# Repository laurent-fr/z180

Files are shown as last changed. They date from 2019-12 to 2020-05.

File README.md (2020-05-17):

# Micro Z180 homebrew computer

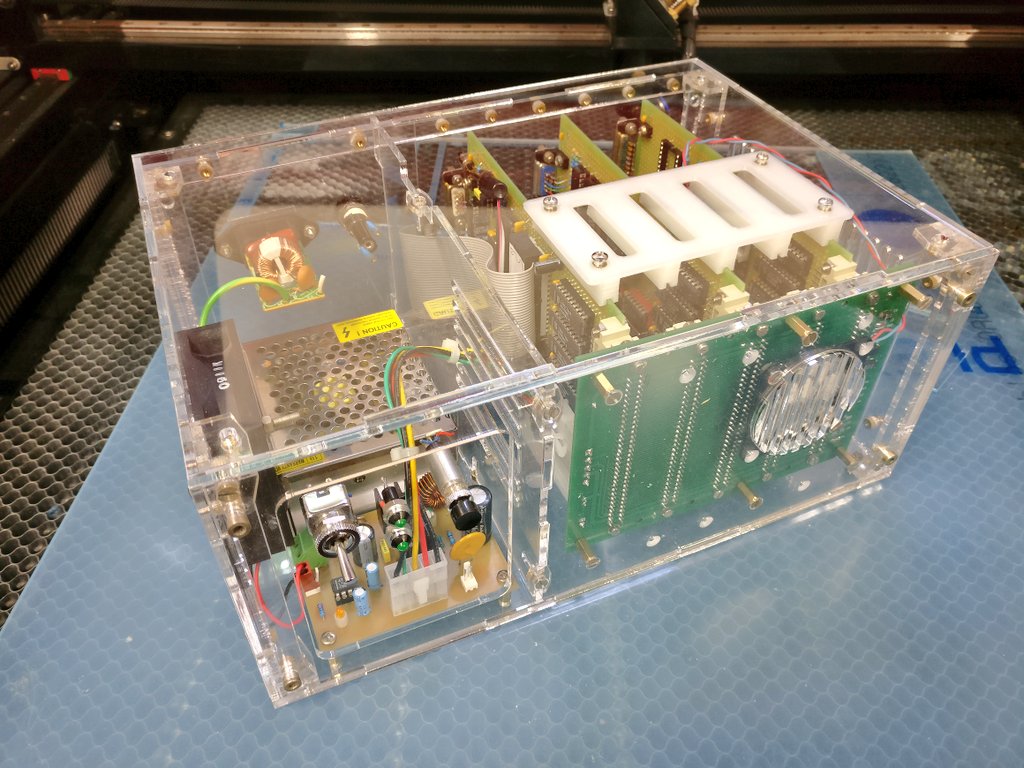
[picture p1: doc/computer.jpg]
The computer


*This is my attempt to create a 80's style computer based on the Zilog Z180 CPU.*

The goal is to build from scratch a complete computer, with  keyboard, video display, and mass storage. The software will be Microsoft BASIC and CP/M. Think of it as a crossover between an Amstrad CPC and an IBM PC 5150 !

The computer is designed around STEBUS, which is an old but well designed 8-bits industry-standard bus (https://en.wikipedia.org/wiki/STEbus). 

For now there are 5 cards :

 * PSU : the power supply, which takes 12v as input and generates +5v and -12v 
 * BUS : the STEBUS base board, with 5 slots and active termination
 * CPU : The main CPU board, with 2 RS-232 connectors
 * VDU : Video display unit, VGA text-only 80x25 with 16 colors, and 8 fonts selectable via jumpers on the board
 * MIO : Multi I/O, including PS/2 keyboard, Real time clock, Sound , Compact flash and Parallel port
 
 There are 3 main folders in this reposirory :
 
 * enclosure : all the files needed to build the case, which is laser-cut 3mm transparent acrylic (all parts are smaller than 200x300 mm), with a 3D printed part to mechanicaly guide the boards.
 * hardware : the description of all boards (very incomplete for now !)
 * software : Tests, BIOS, BASIC, and CP/M (coming soon !)
 
 ## Licenses
 
All the software is GPL v2, and all the hardware is CC-BY-NC-SA
 
 ## Status of the computer
 
 **This is a work-in-progress !**
 
 For now the computer is running BASIC with the PS/2 keyboard and integrated video display. There are still some rough edges but we are almost here.
 
 Some files are not yet on the repository because the computer was designed with paper and pencil !

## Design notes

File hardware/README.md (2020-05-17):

# Hardware

## Software needed

A few softwares are needed for reading/using the files in this folder :

* Kicad for reading the schematics and board layouts  https://kicad-pcb.org/ 
* Quartus 2 web edition for programming the Altera CPLDs https://fpgasoftware.intel.com/13.1/?edition=web
* WinCUPL for programming the GAL of the VDU board https://www.microchip.com/design-centers/fpgas-and-plds/splds-cplds/pld-design-resources

Optional :

* LTSPice, if you want to look at the few simulation files https://www.analog.com/en/design-center/design-tools-and-calculators/ltspice-simulator.html

## Hardware needed for running the computer

* An EPROM programmer. I use a Minipro TL866.
* A JTAG programmer for the CPLDs. I use the super cheap USB Blaster.

## Hardware for debugging the computer

It is not strictly needed to build the computer from the blueprints, but if something goes wrong the following could help :

* An EPROM simulator. The fastest way to test a new firmware ! Mine is a MemSIM2 from http://www.momik.pl/ and it works very well.
* A logic analyzer. Pick your favourite. Mine is a DSLogic.
* A good old oscilloscope is useful, too !

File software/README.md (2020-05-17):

# Software

To assemble the software, you will need SBASM available here : https://www.sbprojects.net/sbasm/

As it is written in Python, you will also need a Python interpreter ...

## BASIC

* nascom.basic.grant.searle : backup of NASCOM BASIC adapted by Grant Searle on his homebrew computer as found on http://searle.x10host.com/z80/SimpleZ80.html
(it's also the base software for RC2014 project)
* original : for reference NASCOM BASIC without modifications
* basic.asm : Grant Searle's version with small modifications by me (skip memory test, add colors)
* basic_boot.asm : the glue between basic.asm and the computer, with memory

## BIOS

The BIOS of the computer.

## CP/M

Work in progress !

## Include

Contains the constants for the Z180.

## mz180

This folder contains the main software for the computer. It allows to boot all-RAM BASIC and hopefully soon CP/M. 
The file eprom.hex is what you want to burn on the EPROM of the CPU board.

## Tests

All what you need to test the computer !

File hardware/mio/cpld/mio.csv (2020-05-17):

# Copyright (C) 1991-2012 Altera Corporation
# Your use of Altera Corporation's design tools | logic functions
# and other software and tools | and its AMPP partner logic
# functions | and any output files from any of the foregoing
# (including device programming or simulation files) | and any
# associated documentation or information are expressly subject
# to the terms and conditions of the Altera Program License
# Subscription Agreement | Altera MegaCore Function License
# Agreement | or other applicable license agreement | including
# without limitation | that your use is for the sole purpose of
# programming logic devices manufactured by Altera and sold by
# Altera or its authorized distributors. Please refer to the
# applicable agreement for further details.
# Quartus II 64-Bit Version 12.1 Build 177 11/07/2012 SJ Web Edition
# File: C:\Users\Laurent\Documents\altera\mio\output_files\mio.csv
# Generated on: Sun May 17 15:32:25 2020
# Note: The column header names should not be changed if you wish to import this .csv file into the Quartus II software.
To | Direction | Location | Fitter Location | Reserved
TCK | Input |  | PIN_32
TDI | Input |  | PIN_7
TDO | Output |  | PIN_38
TMS | Input |  | PIN_13
addr[4] | Input | PIN_4 | PIN_4
addr[3] | Input | PIN_41 | PIN_41
addr[2] | Input | PIN_40 | PIN_40
addr[1] | Input | PIN_39 | PIN_39
addr[0] | Input | PIN_37 | PIN_37
ce | Input | PIN_34 | PIN_34
clk | Input | PIN_43 | PIN_43
cm0 | Input | PIN_31 | PIN_31
cs_compactflash | Output | PIN_26 | PIN_26
cs_printer | Output | PIN_19 | PIN_19
cs_rtc | Output | PIN_21 | PIN_21
data[7] | Bidir | PIN_16 | PIN_16
data[6] | Bidir | PIN_11 | PIN_11
data[5] | Bidir | PIN_14 | PIN_14
data[4] | Bidir | PIN_9 | PIN_9
data[3] | Bidir | PIN_12 | PIN_12
data[2] | Bidir | PIN_8 | PIN_8
data[1] | Bidir | PIN_5 | PIN_5
data[0] | Bidir | PIN_6 | PIN_6
datack | Output | PIN_29 | PIN_29
int | Output | PIN_25 | PIN_25
kbd_clk | Input | PIN_18 | PIN_18
kbd_data | Input | PIN_20 | PIN_20
rd | Output | PIN_27 | PIN_27
reset | Input | PIN_33 | PIN_33
snd | Output | PIN_24 | PIN_24
wr | Output | PIN_28 | PIN_28
divclk | Unknown | PIN_2

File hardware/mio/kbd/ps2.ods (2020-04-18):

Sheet: Feuille1_2
touche | scancode | ascii | ascii+shift | ascii+altgr |  | scancode
 |  |  |  |  | 0 | 0
F9 | 01 |  |  |  | 1 | 1
 |  |  |  |  | 2 | 2
F5 | 03 |  |  |  | 3 | 3
F3 | 04 |  |  |  | 4 | 4
F1 | 05 |  |  |  | 5 | 5
F2 | 06 |  |  |  | 6 | 6
F12 | 07 |  |  |  | 7 | 7
 |  |  |  |  | 8 | 8
F10 | 09 |  |  |  | 9 | 9
F8 | 0a |  |  |  | 10 | A
F6 | 0b |  |  |  | 11 | B
F4 | 0c |  |  |  | 12 | C
tab | 0D | 9 |  |  | 13 | D
₂ | 0E |  |  |  | 14 | E
 |  |  |  |  | 15 | F
 |  |  |  |  | 16 | 10
 |  |  |  |  | 17 | 11
lshift | 12 |  |  |  | 18 | 12
 |  |  |  |  | 19 | 13
 |  |  |  |  | 20 | 14
a | 15 | 97 |  |  | 21 | 15
1 | 16 | 38 | 49 |  | 22 | 16
 |  |  |  |  | 23 | 17
 |  |  |  |  | 24 | 18
 |  |  |  |  | 25 | 19
w | 1A | 119 |  |  | 26 | 1A
s | 1B | 115 |  |  | 27 | 1B
q | 1C | 113 |  |  | 28 | 1C
z | 1D | 122 |  |  | 29 | 1D
2 | 1E |  | 50 | 126 | 30 | 1E
 |  |  |  |  | 31 | 1F
 |  |  |  |  | 32 | 20
c | 21 | 99 |  |  | 33 | 21
x | 22 | 120 |  |  | 34 | 22
d | 23 | 100 |  |  | 35 | 23
e | 24 | 101 |  |  | 36 | 24
4 | 25 | 38 | 52 | 123 | 37 | 25
3 | 26 | 34 | 51 | 35 | 38 | 26
 |  |  |  |  | 39 | 27
 |  |  |  |  | 40 | 28
space | 29 | 32 |  |  | 41 | 29
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

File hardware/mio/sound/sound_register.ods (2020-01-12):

 | Clk
 | 2000000
Freq | Register | Real Freq | Error
27,5 | 72727 | 27,5001031253867 | 0,00 %
29,1352350948806 | 68645 | 29,1354068031175 | 0,00 %
30,8677063285078 | 64793 | 30,86753198648 | 0,00 %
32,7031956625748 | 61156 | 32,7032507031199 | 0,00 %
34,647828872109 | 57724 | 34,6476335666274 | 0,00 %
36,708095989676 | 54484 | 36,7080243741282 | 0,00 %
38,8908729652601 | 51426 | 38,8908334305604 | 0,00 %
41,2034446141088 | 48540 | 41,2031314379893 | 0,00 %
43,6535289291255 | 45815 | 43,6538251664302 | 0,00 %
46,2493028389543 | 43244 | 46,2491906391638 | 0,00 %
48,9994294977187 | 40817 | 48,99919151334 | 0,00 %
51,9130871974932 | 38526 | 51,9129938223537 | 0,00 %
55 | 36364 | 54,9994500054999 | 0,00 %
58,2704701897613 | 34323 | 58,2699647466713 | 0,00 %
61,7354126570155 | 32396 | 61,7360167921966 | 0,00 %
65,4063913251497 | 30578 | 65,4065014062398 | 0,00 %
69,2956577442181 | 28862 | 69,2952671332548 | 0,00 %
73,4161919793519 | 27242 | 73,4160487482564 | 0,00 %
77,7817459305203 | 25713 | 77,7816668611208 | 0,00 %
82,4068892282175 | 24270 | 82,4062628759786 | 0,00 %
87,307057858251 | 22908 | 87,3057447180024 | 0,00 %
92,4986056779087 | 21622 | 92,4983812783276 | 0,00 %
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

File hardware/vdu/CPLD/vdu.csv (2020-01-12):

# Copyright (C) 1991-2012 Altera Corporation
# Your use of Altera Corporation's design tools | logic functions
# and other software and tools | and its AMPP partner logic
# functions | and any output files from any of the foregoing
# (including device programming or simulation files) | and any
# associated documentation or information are expressly subject
# to the terms and conditions of the Altera Program License
# Subscription Agreement | Altera MegaCore Function License
# Agreement | or other applicable license agreement | including
# without limitation | that your use is for the sole purpose of
# programming logic devices manufactured by Altera and sold by
# Altera or its authorized distributors. Please refer to the
# applicable agreement for further details.
# Quartus II 64-Bit Version 12.1 Build 177 11/07/2012 SJ Web Edition
# File: C:\Users\Laurent\Documents\altera\vdu\vdu.csv
# Generated on: Sun Jan 12 18:32:22 2020
# Note: The column header names should not be changed if you wish to import this .csv file into the Quartus II software.
To | Direction | Location | Fitter Location | Reserved
TCK | Input |  | PIN_32
TDI | Input |  | PIN_7
TDO | Output |  | PIN_38
TMS | Input |  | PIN_13
addr[10] | Output | PIN_20 | PIN_20
addr[9] | Output | PIN_21 | PIN_21
addr[8] | Output | PIN_18 | PIN_18
addr[7] | Output | PIN_19 | PIN_19
addr[6] | Output | PIN_16 | PIN_16
addr[5] | Output | PIN_14 | PIN_14
addr[4] | Output | PIN_11 | PIN_11
addr[3] | Output | PIN_12 | PIN_12
addr[2] | Output | PIN_9 | PIN_9
addr[1] | Output | PIN_8 | PIN_8
addr[0] | Output | PIN_6 | PIN_6
blank | Output | PIN_5 | PIN_5
clk | Input | PIN_43 | PIN_43
cload | Output | PIN_4 | PIN_4
cs | Input | PIN_33 | PIN_33
datack | Output | PIN_29 | PIN_29
hsync | Output | PIN_40 | PIN_40
row[3] | Output | PIN_25 | PIN_25
row[2] | Output | PIN_24 | PIN_24
row[1] | Output | PIN_27 | PIN_27
row[0] | Output | PIN_26 | PIN_26
vclk | Input | PIN_2 | PIN_2
vsync | Output | PIN_41 | PIN_41

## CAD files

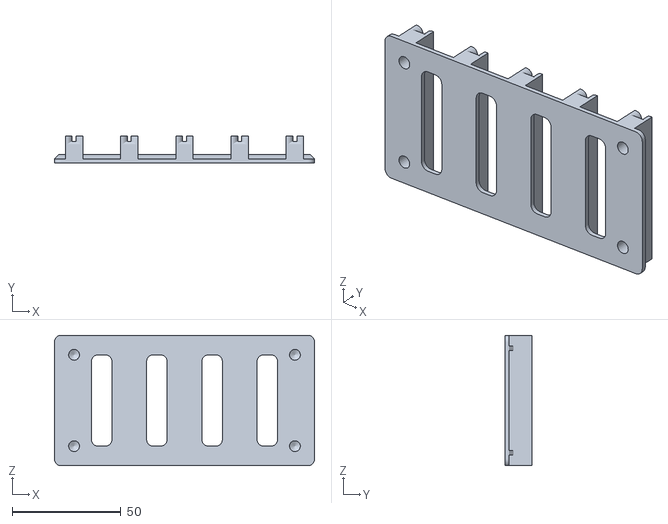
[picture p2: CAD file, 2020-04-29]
enclosure/3dprint/card_guide.stl
119.6 x 12.2 x 60.0

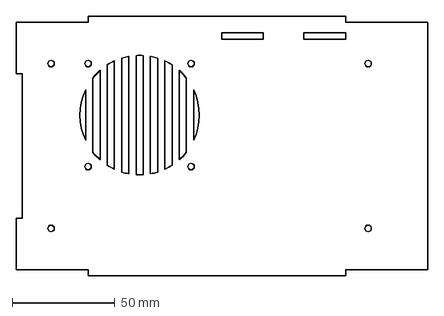
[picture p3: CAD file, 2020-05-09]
enclosure/lasercut/side_left.dxf
200.0 x 126.0 mm

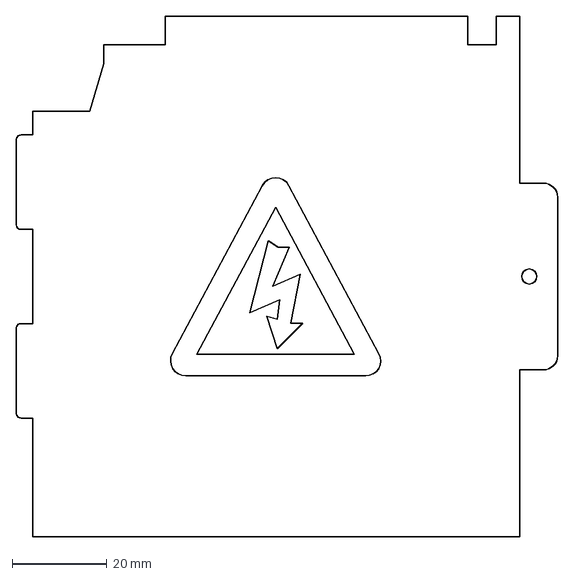
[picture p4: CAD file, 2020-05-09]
enclosure/lasercut/top_psu.dxf
114.5 x 110.0 mm

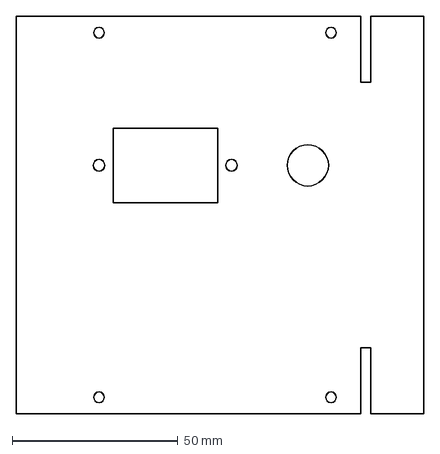
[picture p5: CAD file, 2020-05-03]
enclosure/lasercut/back_psu.dxf
123.0 x 120.0 mm

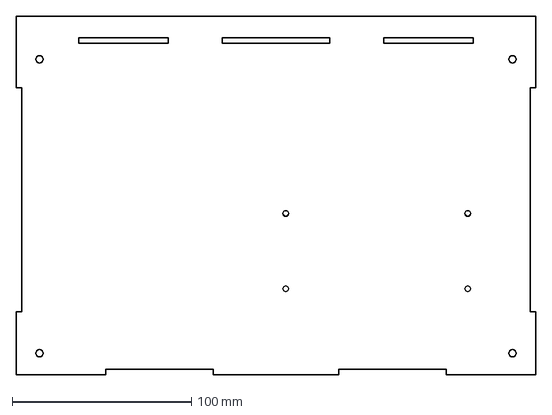
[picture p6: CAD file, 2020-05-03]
enclosure/lasercut/top.dxf
290.0 x 200.0 mm

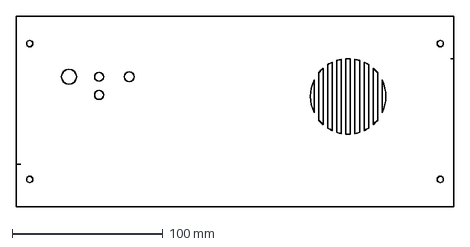
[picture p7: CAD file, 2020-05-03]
enclosure/lasercut/front.dxf
290.0 x 126.0 mm

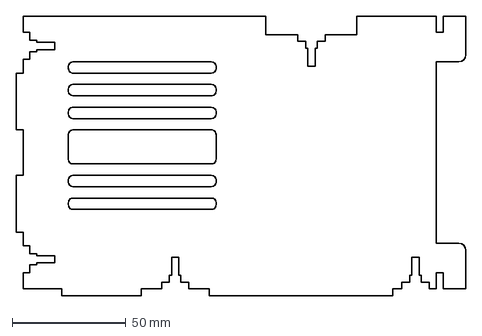
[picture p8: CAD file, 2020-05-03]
enclosure/lasercut/inner_wall.dxf
198.0 x 123.0 mm

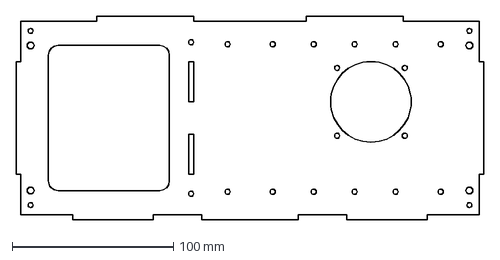
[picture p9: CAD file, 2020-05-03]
enclosure/lasercut/front_in.dxf
290.0 x 126.0 mm

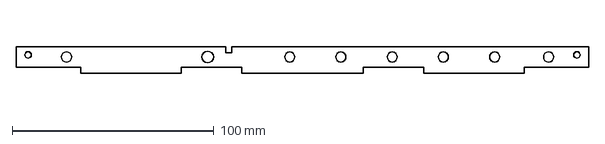
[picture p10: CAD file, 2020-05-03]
enclosure/lasercut/back.dxf
284.0 x 13.0 mm

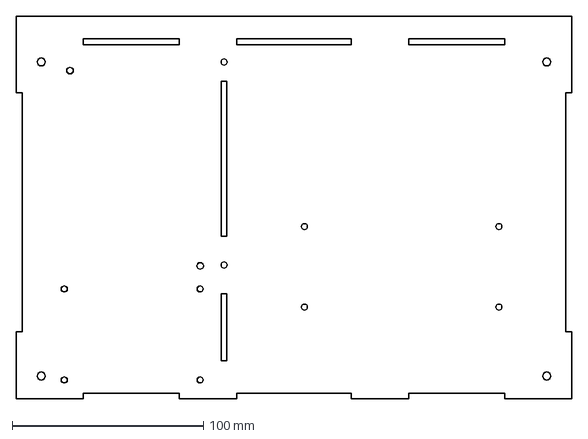
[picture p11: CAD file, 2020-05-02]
enclosure/lasercut/bottom.dxf
290.0 x 200.0 mm

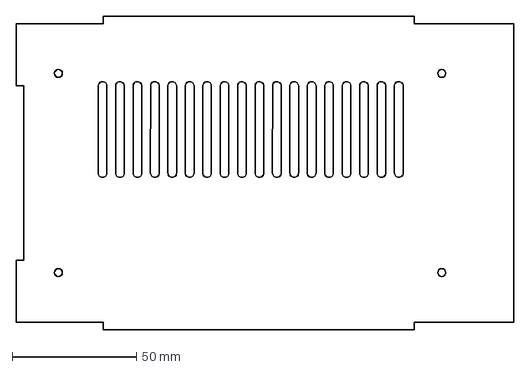
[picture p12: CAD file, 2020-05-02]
enclosure/lasercut/side_right.dxf
200.0 x 126.0 mm

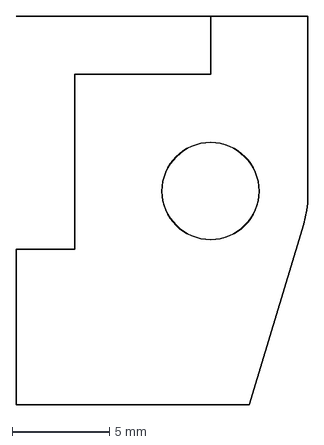
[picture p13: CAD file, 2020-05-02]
enclosure/lasercut/corner_top_bottom.dxf
15.0 x 20.0 mm

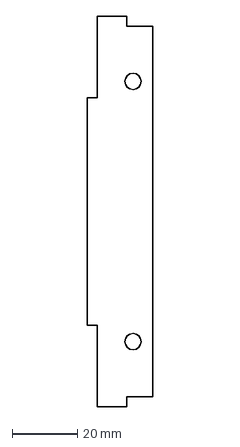
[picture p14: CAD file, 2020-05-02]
enclosure/lasercut/corner_side.dxf
20.0 x 120.0 mm

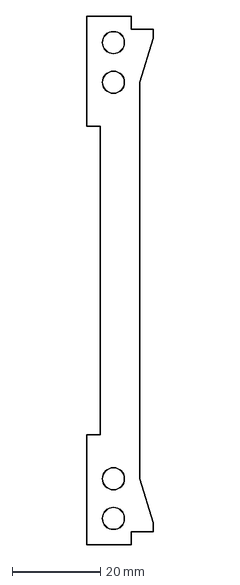
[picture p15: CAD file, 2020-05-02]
enclosure/lasercut/corner_front.dxf
15.0 x 120.0 mm

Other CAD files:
enclosure/lasercut/bolt.dxf

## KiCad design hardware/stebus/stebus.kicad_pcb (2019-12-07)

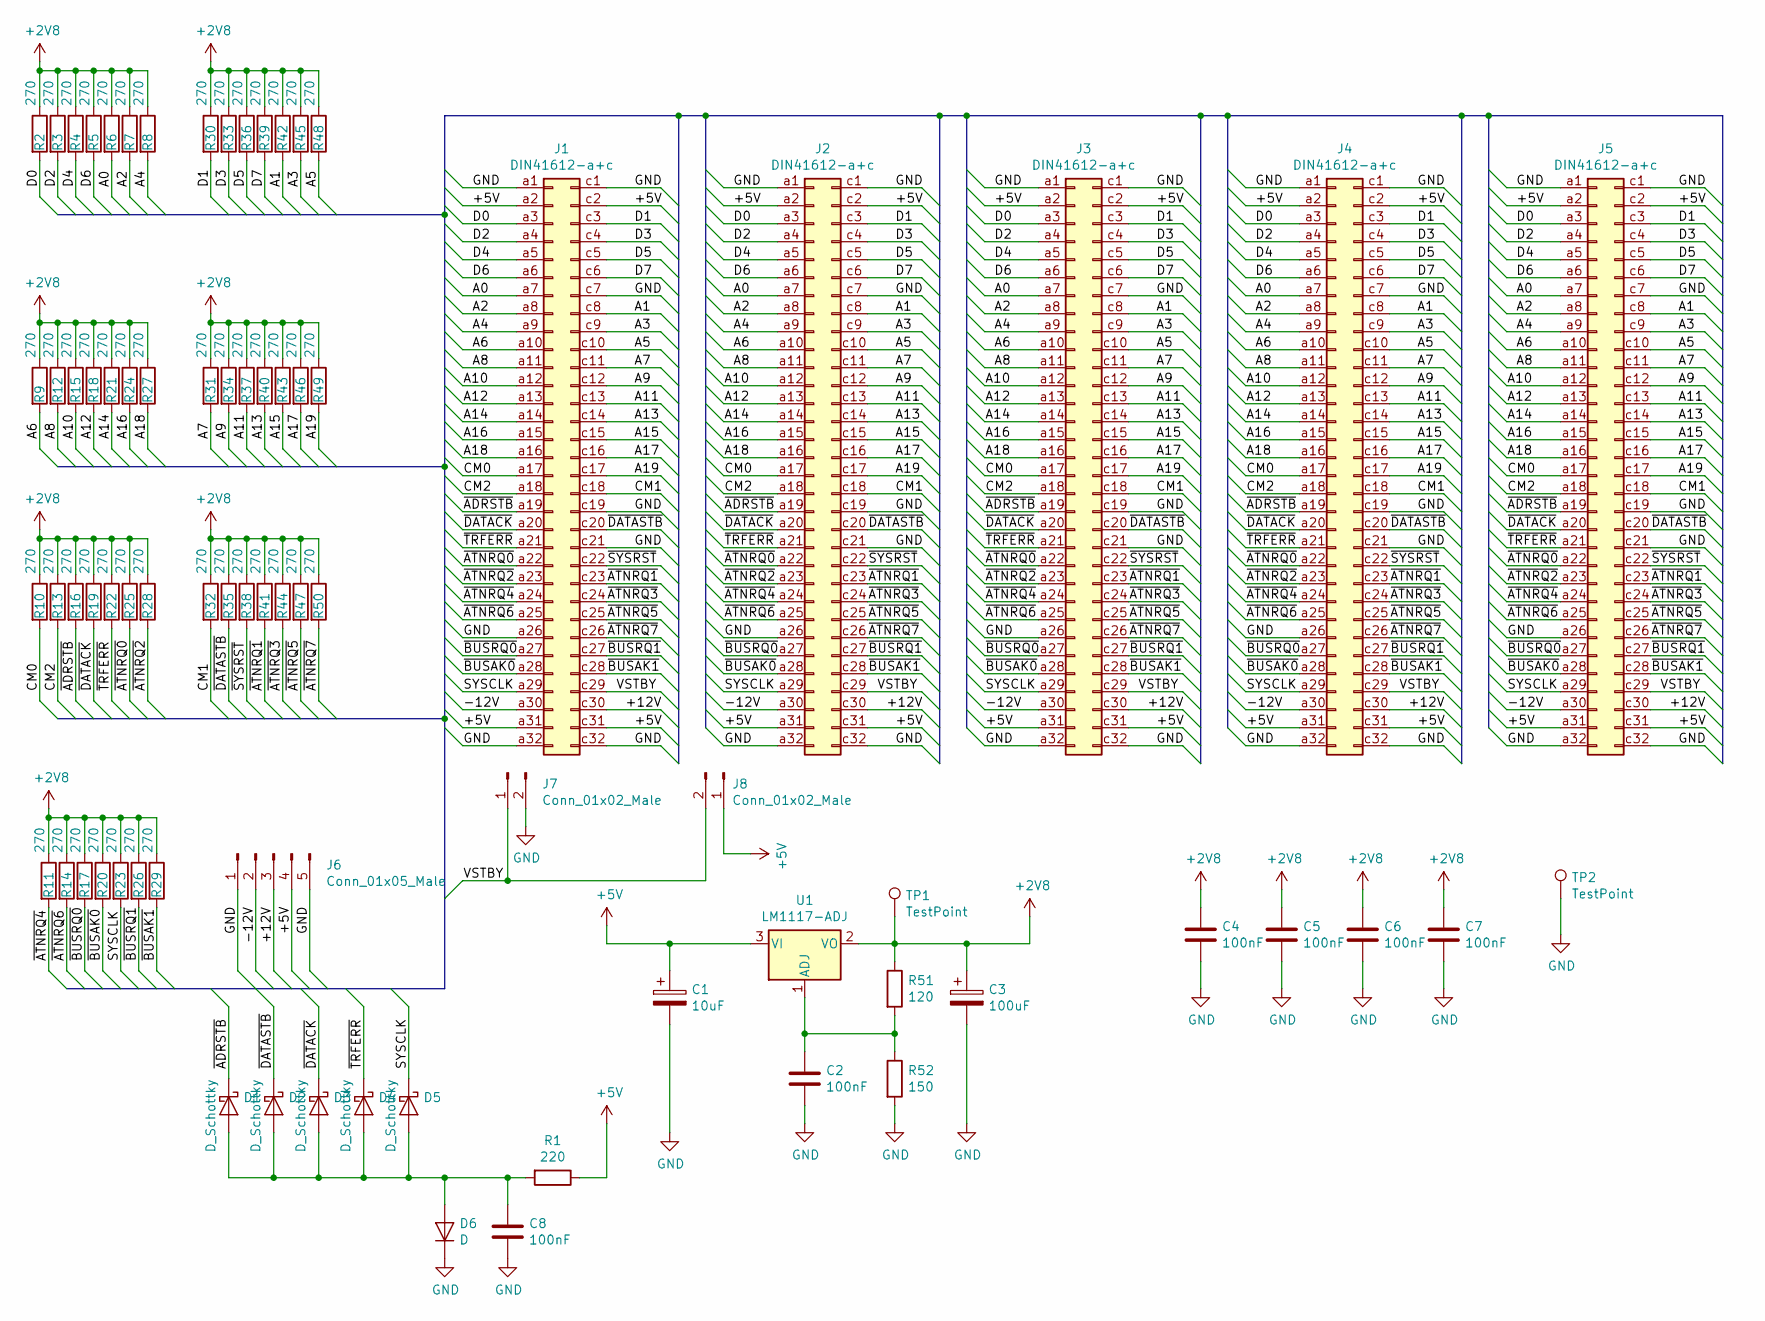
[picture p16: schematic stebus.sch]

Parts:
C1: 10uF; C_1210_HandSoldering
C2, C4, C5, C6, C7, C8: 100nF; C_1206_HandSoldering
C3: 100uF; C_1812_HandSoldering
D1, D2, D3, D4, D5: D_Schottky; D_SMA
D6: D; D_MiniMELF_Handsoldering
J1, J2, J3, J4, J5: DIN41612-a+c; Socket_DIN41612-CaseC1-AC-Female-64Pin-2rows
J6: Conn_01x05_Male; Molex_MiniFit-JR-5556-10A_1x05x4.20mm_Straight
J7: Conn_01x02_Male; Molex_KK-6410-02_02x2.54mm_Straight
J8: Conn_01x02_Male; Pin_Header_Straight_1x02_Pitch2.54mm
R1: 220; R_1206_HandSoldering
R2, R3, R4, R5, R6, R7, R8, R9, R10, R11, R12, R13, R14, R15, R16, R17, R18, R19, R20, R21, R22, R23, R24, R25, R26, R27, R28, R29, R30, R31, R32, R33, R34, R35, R36, R37, R38, R39, R40, R41, R42, R43, R44, R45, R46, R47, R48, R49, R50: 270; R_1206_HandSoldering
R51: 120; C_1206_HandSoldering
R52: 150; C_1206_HandSoldering
TP1, TP2: TestPoint; Pin_Header_Straight_1x01_Pitch2.54mm
U1: LM1117-ADJ; SOT-223-3_TabPin2

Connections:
+2V8: C3.1, C4.1, C5.1, C6.1, C7.1, R2.1, R3.1, R4.1, R5.1, R6.1, R7.1, R8.1, R9.1, R10.1, R11.1, R12.1, R13.1, R14.1, R15.1, R16.1, R17.1, R18.1, R19.1, R20.1, R21.1, R22.1, R23.1, R24.1, R25.1, R26.1, R27.1, R28.1, R29.1, R30.1, R31.1, R32.1, R33.1, R34.1, R35.1, R36.1, R37.1, R38.1, R39.1, R40.1, R41.1, R42.1, R43.1, R44.1, R45.1, R46.1, R47.1, R48.1, R49.1, R50.1, R51.1, TP1.1, U1.2 (VO)
+5V: C1.1, J1.a2, J1.a31, J1.c2, J1.c31, J2.a2, J2.a31, J2.c2, J2.c31, J3.a2, J3.a31, J3.c2, J3.c31, J4.a2, J4.a31, J4.c2, J4.c31, J5.a2, J5.a31, J5.c2, J5.c31, J6.4, J8.1, R1.1, U1.3 (VI)
/+12V: J1.c30, J2.c30, J3.c30, J4.c30, J5.c30, J6.3
/-12V: J1.a30, J2.a30, J3.a30, J4.a30, J5.a30, J6.2
/A0: J1.a7, J2.a7, J3.a7, J4.a7, J5.a7, R6.2
/A1: J1.c8, J2.c8, J3.c8, J4.c8, J5.c8, R42.2
/A2: J1.a8, J2.a8, J3.a8, J4.a8, J5.a8, R7.2
/A3: J1.c9, J2.c9, J3.c9, J4.c9, J5.c9, R45.2
/A4: J1.a9, J2.a9, J3.a9, J4.a9, J5.a9, R8.2
/A5: J1.c10, J2.c10, J3.c10, J4.c10, J5.c10, R48.2
/A6: J1.a10, J2.a10, J3.a10, J4.a10, J5.a10, R9.2
/A7: J1.c11, J2.c11, J3.c11, J4.c11, J5.c11, R31.2
/A8: J1.a11, J2.a11, J3.a11, J4.a11, J5.a11, R12.2
/A9: J1.c12, J2.c12, J3.c12, J4.c12, J5.c12, R34.2
/A10: J1.a12, J2.a12, J3.a12, J4.a12, J5.a12, R15.2
/A11: J1.c13, J2.c13, J3.c13, J4.c13, J5.c13, R37.2
/A12: J1.a13, J2.a13, J3.a13, J4.a13, J5.a13, R18.2
/A13: J1.c14, J2.c14, J3.c14, J4.c14, J5.c14, R40.2
/A14: J1.a14, J2.a14, J3.a14, J4.a14, J5.a14, R21.2
/A15: J1.c15, J2.c15, J3.c15, J4.c15, J5.c15, R43.2
/A16: J1.a15, J2.a15, J3.a15, J4.a15, J5.a15, R24.2
/A17: J1.c16, J2.c16, J3.c16, J4.c16, J5.c16, R46.2
/A18: J1.a16, J2.a16, J3.a16, J4.a16, J5.a16, R27.2
/A19: J1.c17, J2.c17, J3.c17, J4.c17, J5.c17, R49.2
/CM0: J1.a17, J2.a17, J3.a17, J4.a17, J5.a17, R10.2
/CM1: J1.c18, J2.c18, J3.c18, J4.c18, J5.c18, R32.2
/CM2: J1.a18, J2.a18, J3.a18, J4.a18, J5.a18, R13.2
/D0: J1.a3, J2.a3, J3.a3, J4.a3, J5.a3, R2.2
/D1: J1.c3, J2.c3, J3.c3, J4.c3, J5.c3, R30.2
/D2: J1.a4, J2.a4, J3.a4, J4.a4, J5.a4, R3.2
/D3: J1.c4, J2.c4, J3.c4, J4.c4, J5.c4, R33.2
/D4: J1.a5, J2.a5, J3.a5, J4.a5, J5.a5, R4.2
/D5: J1.c5, J2.c5, J3.c5, J4.c5, J5.c5, R36.2
/D6: J1.a6, J2.a6, J3.a6, J4.a6, J5.a6, R5.2
/D7: J1.c6, J2.c6, J3.c6, J4.c6, J5.c6, R39.2
/SYSCLK: D5.1 (K), J1.a29, J2.a29, J3.a29, J4.a29, J5.a29, R23.2
/VSTBY: J1.c29, J2.c29, J3.c29, J4.c29, J5.c29, J7.1, J8.2
/~: J1.a25, J2.a25, J3.a25, J4.a25, J5.a25, R14.2
/~ADRSTB~: D1.1 (K), J1.a19, J2.a19, J3.a19, J4.a19, J5.a19, R16.2
/~ATNRQ0~: J1.a22, J2.a22, J3.a22, J4.a22, J5.a22, R25.2
/~ATNRQ1~: J1.c23, J2.c23, J3.c23, J4.c23, J5.c23, R41.2
/~ATNRQ2~: J1.a23, J2.a23, J3.a23, J4.a23, J5.a23, R28.2
/~ATNRQ3~: J1.c24, J2.c24, J3.c24, J4.c24, J5.c24, R44.2
/~ATNRQ4~: J1.a24, J2.a24, J3.a24, J4.a24, J5.a24, R11.2
/~ATNRQ5~: J1.c25, J2.c25, J3.c25, J4.c25, J5.c25, R47.2
/~ATNRQ7~: J1.c26, J2.c26, J3.c26, J4.c26, J5.c26, R50.2
/~BUSAK0~: J1.a28, J2.a28, J3.a28, J4.a28, J5.a28, R20.2
/~BUSAK1~: J1.c28, J2.c28, J3.c28, J4.c28, J5.c28, R29.2
/~BUSRQ0~: J1.a27, J2.a27, J3.a27, J4.a27, J5.a27, R17.2
/~BUSRQ1~: J1.c27, J2.c27, J3.c27, J4.c27, J5.c27, R26.2
/~DATACK~: D3.1 (K), J1.a20, J2.a20, J3.a20, J4.a20, J5.a20, R19.2
/~DATASTB~: D2.1 (K), J1.c20, J2.c20, J3.c20, J4.c20, J5.c20, R35.2
/~SYSRST~: J1.c22, J2.c22, J3.c22, J4.c22, J5.c22, R38.2
/~TRFERR~: D4.1 (K), J1.a21, J2.a21, J3.a21, J4.a21, J5.a21, R22.2
GND: C1.2, C2.2, C3.2, C4.2, C5.2, C6.2, C7.2, C8.2, D6.1 (K), J1.a1, J1.a26, J1.a32, J1.c1, J1.c7, J1.c19, J1.c21, J1.c32, J2.a1, J2.a26, J2.a32, J2.c1, J2.c7, J2.c19, J2.c21, J2.c32, J3.a1, J3.a26, J3.a32, J3.c1, J3.c7, J3.c19, J3.c21, J3.c32, J4.a1, J4.a26, J4.a32, J4.c1, J4.c7, J4.c19, J4.c21, J4.c32, J5.a1, J5.a26, J5.a32, J5.c1, J5.c7, J5.c19, J5.c21, J5.c32, J6.1, J6.5, J7.2, R52.2, TP2.1
unnamed: C2.1, R51.2, R52.1, U1.1 (ADJ)
unnamed: C8.1, D1.2 (A), D2.2 (A), D3.2 (A), D4.2 (A), D5.2 (A), D6.2 (A), R1.2

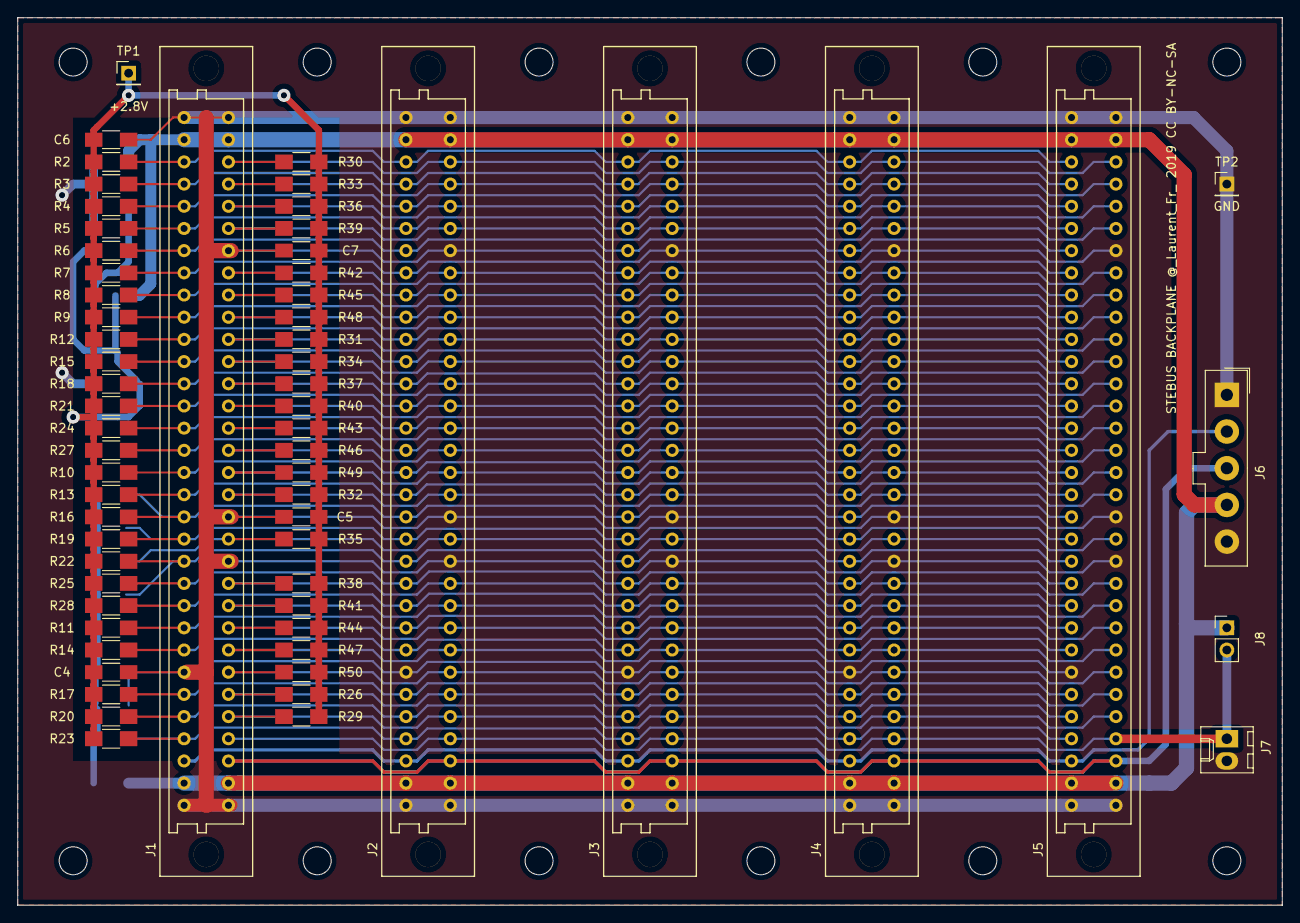
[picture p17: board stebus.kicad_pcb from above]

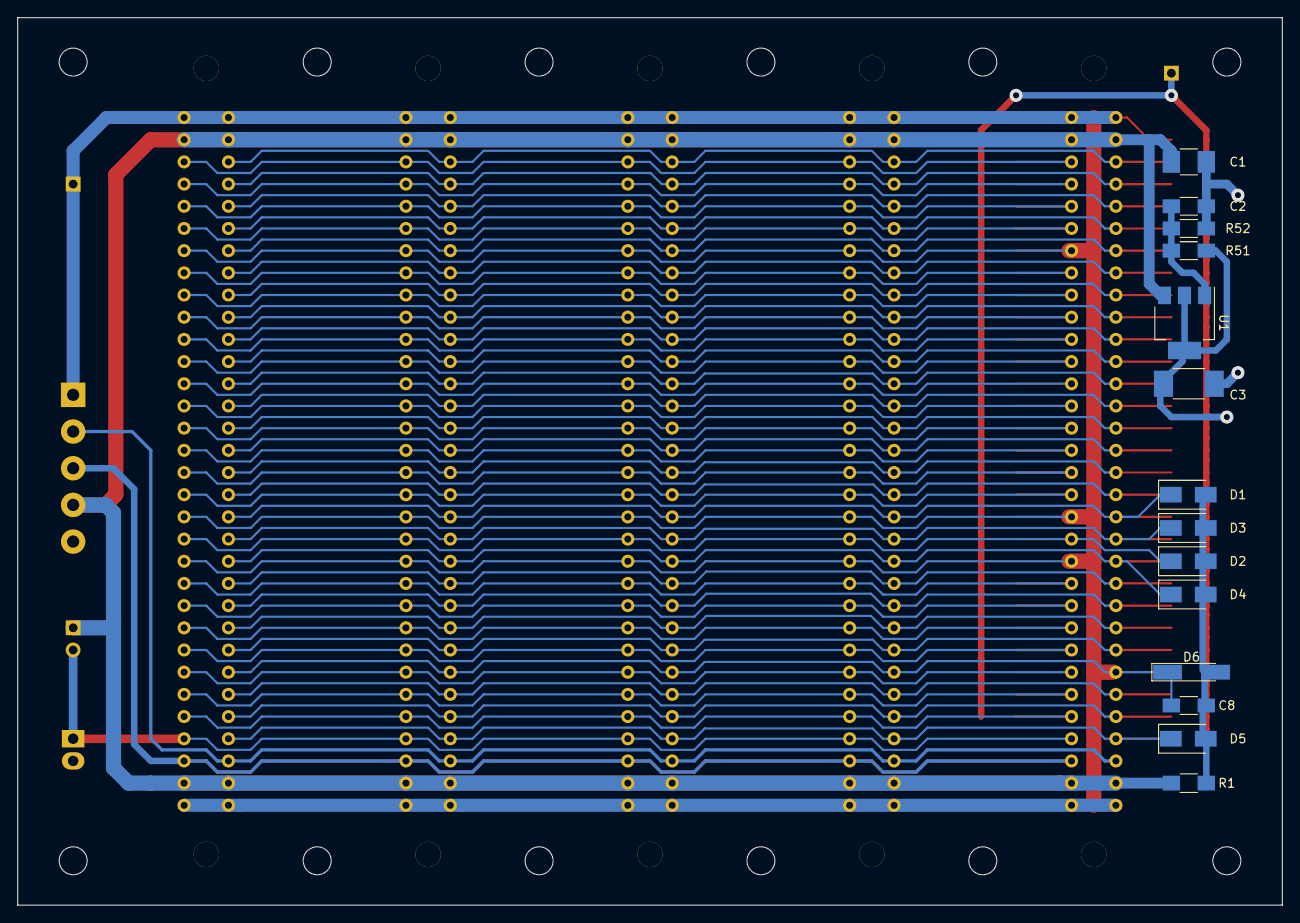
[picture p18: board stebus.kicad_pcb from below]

Board: 2 copper layers, 144.8 x 101.6 mm, 77 parts (14 on the bottom side), 57 nets.

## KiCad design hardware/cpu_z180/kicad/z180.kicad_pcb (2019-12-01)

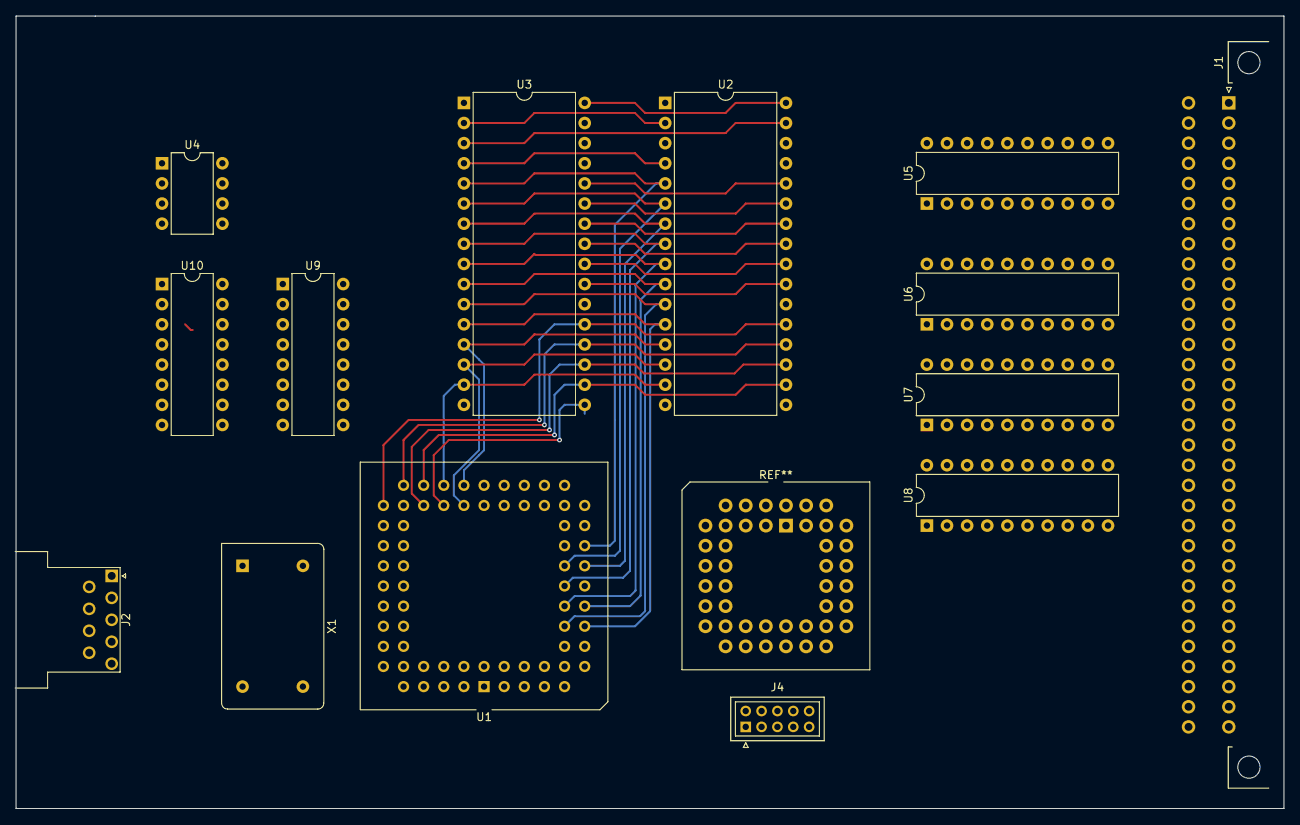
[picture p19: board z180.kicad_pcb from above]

Board: 2 copper layers, 160.0 x 100.0 mm, 14 parts (0 on the bottom side), 61 nets.

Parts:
J1: DIN41612-a+c; DIN41612_A+C_2x32_Horizontal
J2: DB9_Male_MountingHoles; DSUB-9_Male_Horizontal_P2.77x2.84mm_EdgePinOffset9.40mm
J4: Conn_02x05_Counter_Clockwise; JAE_LY20-10P-2T_2x05x2.00mm_Straight
U1: Z8S180CPU; PLCC-68_THT-Socket
U2: AS6C4008-55PCN; DIP-32_W15.24mm
U3: 27C010; DIP-32_W15.24mm
U4: TL7705B; DIP-8_W7.62mm
U5, U6, U7, U8: 74HC245; DIP-20_W7.62mm
U9, U10: MAX232; DIP-16_W7.62mm
X1: ACO-xxxMHz; Oscillator_DIP-14

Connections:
+5V: J1.a2, J1.a31, J1.c2, J1.c31, U1.34, U2.32, U3.31, U3.32, U5.20, X1.14
/bus-z180/BUS_A0: J1.a7, U6.18
/bus-z180/BUS_A1: J1.c8, U6.17
/bus-z180/BUS_A2: J1.a8, U6.16
/bus-z180/BUS_A3: J1.c9, U6.15
/bus-z180/BUS_A4: J1.a9, U6.14
/bus-z180/BUS_A5: J1.c10, U6.13
/bus-z180/BUS_A6: J1.a10, U6.12
/bus-z180/BUS_A7: J1.c11, U6.11
/bus-z180/BUS_A8: J1.a11, U7.18
/bus-z180/BUS_A9: J1.c12, U7.17
/bus-z180/BUS_A10: J1.a12, U7.16
/bus-z180/BUS_A11: J1.c13, U7.15
/bus-z180/BUS_A12: J1.a13, U7.14
/bus-z180/BUS_A13: J1.c14, U7.13
/bus-z180/BUS_A14: J1.a14, U7.12
/bus-z180/BUS_A15: J1.c15, U7.11
/bus-z180/BUS_A16: J1.a15, U8.18
/bus-z180/BUS_A17: J1.c16, U8.17
/bus-z180/BUS_A18: J1.a16, U8.16
/bus-z180/BUS_A19: J1.c17, U8.15
/bus-z180/BUS_D0: J1.a3, U5.18
/bus-z180/BUS_D1: J1.c3, U5.17
/bus-z180/BUS_D2: J1.a4, U5.16
/bus-z180/BUS_D3: J1.c4, U5.15
/bus-z180/BUS_D4: J1.a5, U5.14
/bus-z180/BUS_D5: J1.c5, U5.13
/bus-z180/BUS_D6: J1.a6, U5.12
/bus-z180/BUS_D7: J1.c6, U5.11
/~RD~: U1.67, U2.24, U3.24
/~WR~: U1.66, U2.29
A0: U1.14, U2.12, U3.12, U6.2
A1: U1.15, U2.11, U3.11, U6.3
A2: U1.16, U2.10, U3.10, U6.4
A3: U1.17, U2.9, U3.9, U6.5
A4: U1.19, U2.8, U3.8, U6.6
A5: U1.20, U2.7, U3.7, U6.7
A6: U1.21, U2.6, U3.6, U6.8
A7: U1.22, U2.5, U3.5, U6.9
A8: U1.23, U2.27, U3.27, U7.2
A9: U1.24, U2.26, U3.26, U7.3
A10: U1.25, U2.23, U3.23, U7.4
A11: U1.26, U2.25, U3.25, U7.5
A12: U1.27, U2.4, U3.4, U7.6
A13: U1.28, U2.28, U3.28, U7.7
A14: U1.29, U2.3, U3.29, U7.8
A15: U1.30, U2.31, U3.3, U7.9
A16: U1.31, U2.2, U3.2, U8.2
A17: U1.32, U2.30, U8.3
A18: U1.33, U2.1, U8.4
A19: U1.35, U8.5
D0: U1.37, U2.13, U3.13, U5.2
D1: U1.38, U2.14, U3.14, U5.3
D2: U1.39, U2.15, U3.15, U5.4
D3: U1.40, U2.17, U3.17, U5.5
D4: U1.41, U2.18, U3.18, U5.6
D5: U1.42, U2.19, U3.19, U5.7
D6: U1.43, U2.20, U3.20, U5.8
D7: U1.44, U2.21, U3.21, U5.9
GND: J1.a1, J1.a26, J1.a32, J1.c1, J1.c7, J1.c19, J1.c21, J1.c32, U1.1, U1.2, U1.18, U1.36, U2.16, U3.1, U3.16, U5.10, X1.7
unnamed: U1.4, X1.8

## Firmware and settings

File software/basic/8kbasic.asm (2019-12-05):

; NASCOM ROM BASIC Ver 4.7, (C) 1978 Microsoft
; Scanned from source published in 80-BUS NEWS from Vol 2, Issue 3
; (May-June 1983) to Vol 3, Issue 3 (May-June 1984)
; Adapted for the freeware Zilog Macro Assembler 2.10 to produce
; the original ROM code (checksum 0xA934). PA

.z180

.area CODE (ABS)


; MONITOR EQUATES (RESTART INSTRUCTIONS)

_ROUT   .equ     0xF7            ; ROUT - Output char in A
_BLNK   .equ     0x7BDF          ; SCAL BLINK - Get input char in A
_INLN   .equ     0x63DF          ; SCAL INLIN - Get input line
_MFLP   .equ     0x5FDF          ; SCAL MFLP - Toggle tape drv LED
_MRET   .equ     0x5BDF          ; SCAL MRET - Return to monitor
_READ   .equ     0x52DF          ; SCAL READ
_RIN    .equ     0x62DF          ; SCAL RIN - Scan for input char
_VRFY   .equ     0x56DF          ; SCAL VERIFY
_WRIT   .equ     0x57DF          ; SCAL WRITE

; GENERAL .equATES

UARTD   .equ     0x01             ; UART data port
UARTS   .equ     0x02             ; UART status port
CTRLC   .equ     0x03             ; Control "C"
CTRLG   .equ     0x07             ; Control "G"
BKSP    .equ     0x08             ; Back space
LF      .equ     0x0A             ; Line feed
CS      .equ     0x0C             ; Clear screen
CR      .equ     0x0D             ; Carriage return
CTRLO   .equ     0x0F             ; Control "O"
CTRLR   .equ     0x12             ; Control "R"
CTRLS   .equ     0x13             ; Control "S"
CTRLU   .equ     0x15             ; Control "U"
CTRLZ   .equ     0x1A             ; Control "Z"
ESC     .equ     0x1B             ; Escape
TBRK    .equ     0x1C             ; "T" monitor break
TBS     .equ     0x1D             ; "T" monitor back space
TCS     .equ     0x1E             ; "T" monitor clear screen
TCR     .equ     0x1F             ; "T" monitor carriage return
DEL     .equ     0x7F             ; Delete

; MONITOR LOCATIONS

MONSTT  .equ     0x0000           ; Start of monitor
STMON   .equ     0x000D           ; NAS-SYS initialisation
MFLP    .equ     0x0051           ; Flip tape LED ("T")
MONTYP  .equ     0x008D           ; Type of "T" monitor
T2DUMP  .equ     0x03D1           ; "T2" Dump routine
T4WR    .equ     0x0400           ; "T4" Write routine
T4READ  .equ     0x070C           ; "T4" Read routine
VDU     .equ     0x0800           ; NASCOM Video RAM base

; MONITOR WORK SPACE LOCATIONS

PORT0   .equ     0x0C00           ; Copy of output port 0
ARG1    .equ     0x0C0C           ; Argument 1
ARG2    .equ     0x0C0E           ; Argument 2
TCUR    .equ     0x0C18           ; "T" monitor cursor
CURSOR  .equ     0x0C29           ; NAS-SYS Cursor
ARGN    .equ     0x0C2B           ; Number of ARGS
TOUT    .equ     0x0C4A           ; "T" Output reflection
TIN     .equ     0x0C4D           ; "T" Input reflection
CIN     .equ     0x0C75           ; NAS-SYS Input table
NMI     .equ     0x0C7E           ; NAS-SYS NMI Jump

; BASIC WORK SPACE LOCATIONS

WRKSPC  .equ     0x1000           ; BASIC Work space
USR     .equ     0x1003           ; "USR (x)" jump
OUTSUB  .equ     0x1006           ; "OUT p,n"
OTPORT  .equ     0x1007           ; Port (p)
DIVSUP  .equ     0x1009           ; Division support routine
DIV1    .equ     0x100A           ; <- Values
DIV2    .equ     0x100E           ; <-   to
DIV3    .equ     0x1012           ; <-   be
DIV4    .equ     0x1015           ; <-inserted
SEED    .equ     0x1017           ; Random number seed
LSTRND  .equ     0x103A           ; Last random number
INPSUB  .equ     0x103E           ; #INP (x)" Routine
INPORT  .equ     0x103F           ; PORT (x)
NULLS   .equ     0x1041           ; Number of nulls
LWIDTH  .equ     0x1042           ; Terminal width
COMMAN  .equ     0x1043           ; Width for commas
NULFLG  .equ     0x1044           ; Null after input byte flag
CTLOFG  .equ     0x1045           ; Control "O" flag
LINESC  .equ     0x1046           ; Lines counter
LINESN  .equ     0x1048           ; Lines number
CHKSUM  .equ     0x104A           ; Array load/save check sum
NMIFLG  .equ     0x104C           ; Flag for NMI break routine
BRKFLG  .equ     0x104D           ; Break flag
RINPUT  .equ     0x104E           ; Input reflection
POINT   .equ     0x1051           ; "POINT" reflection (unused)
PSET    .equ     0x1054           ; "SET"   reflection
RESET   .equ     0x1057           ; "RESET" reflection
STRSPC  .equ     0x105A           ; Bottom of string space
LINEAT  .equ     0x105C           ; Current line number
BASTXT  .equ     0x105E           ; Pointer to start of program
BUFFER  .equ     0x1061           ; Input buffer
STACK   .equ     0x1066           ; Initial stack
CURPOS  .equ     0x10AB           ; Character position on line
LCRFLG  .equ     0x10AC           ; Locate/Create flag
TYPE    .equ     0x10AD           ; Data type flag
DATFLG  .equ     0x10AE           ; Literal statement flag
LSTRAM  .equ     0x10AF           ; Last available RAM
TMSTPT  .equ     0x10B1           ; Temporary string pointer
TMSTPL  .equ     0x10B3           ; Temporary string pool
TMPSTR  .equ     0x10BF           ; Temporary string
STRBOT  .equ     0x10C3           ; Bottom of string space
CUROPR  .equ     0x10C5           ; Current operator in EVAL
LOOPST  .equ     0x10C7           ; First statement of loop
DATLIN  .equ     0x10C9           ; Line of current DATA item
FORFLG  .equ     0x10CB           ; "FOR" loop flag
LSTBIN  .equ     0x10CC           ; Last byte entered
READFG  .equ     0x10CD           ; Read/Input flag
BRKLIN  .equ     0x10CE           ; Line of break
NXTOPR  .equ     0x10D0           ; Next operator in EVAL
ERRLIN  .equ     0x10D2           ; Line of error
CONTAD  .equ     0x10D4           ; Where to CONTinue
PROGND  .equ     0x10D6           ; End of program
VAREND  .equ     0x10D8           ; End of variables
ARREND  .equ     0x10DA           ; End of arrays
NXTDAT  .equ     0x10DC           ; Next data item
FNRGNM  .equ     0x10DE           ; Name of FN argument
FNARG   .equ     0x10E0           ; FN argument value
FPREG   .equ     0x10E4           ; Floating point register
FPEXP   .equ     FPREG+3         ; Floating point exponent
SGNRES  .equ     0x10E8           ; Sign of result
PBUFF   .equ     0x10E9           ; Number print buffer
MULVAL  .equ     0x10F6           ; Multiplier
PROGST  .equ     0x10F9           ; Start of program text area
STLOOK  .equ     0x115D           ; Start of memory test

; BASIC ERROR CODE VALUES
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

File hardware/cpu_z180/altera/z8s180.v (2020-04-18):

module z8s180    (
    
	 //clk
	 input clk,
	 
	 // chip select
	 output cs_ram,
	 output cs_rom,
	 output cs_stebus,
	 input [2:0] addr,
	 
	 // mem rd/wr
	 output mem_rd,
	 output mem_wr,
	 
	 // stebus
	 output cm0,
	 output cm1,
	 output cm2,
	 output adrstrb,
	 output datastrb,
	 input datack,
	 input trferr,
	 
	 // bus dir
	 output busdir, // 0: output , 1: input 
	 
	 // cpu
	 input iorq,
	 input mreq,
	 input m1,
	 input wr,
	 input rd,
	 output zwait
    
	 );
	 
	 reg r_cm0, r_cm1, r_cm2, r_adrstrobe,r_datastrobe;
	
	 reg r_wait =1'b1;
	 
	 reg[2:0] waits = 3'b00;
	 
	 assign cs_ram = ~addr[2]; // A19..A17 == 1xx
	 assign cs_rom = addr[2] | addr[1] | addr[0]; // A19..A17 == 000
	 assign cs_stebus = ~((addr>0) & (addr<4)) & iorq ;  
	 //assign cs_stebus = 0; // TMP
	 
	 assign mem_rd = mreq | rd;
	 assign mem_wr = mreq | wr;
  
	 assign cm0=r_cm0;
	 assign cm1=r_cm1;
	 assign cm2=r_cm2;
	 assign adrstrb=r_adrstrobe;
	 assign datastrb=r_datastrobe;
	 assign zwait=r_wait;
	 
	 assign busdir=~rd; 
  
	 always @(posedge clk)
	 begin
		r_cm0 <= ~rd ;
		r_cm1 <= ~mreq ;
	   r_cm2 <= ~cs_stebus ;
		r_adrstrobe <= (mreq & iorq ) ; 
	   r_datastrobe <= (rd & wr ) ;
	 end
	
	
	always @(posedge clk)
	 begin	
		// RAM = 1 wait state
		if ( cs_ram == 0 ) 
		begin 
			case (waits)
				3'b000:
					if ((mreq == 0) & ( (rd==0)|(wr==0)) )
					begin
						r_wait <= 0;
						waits <= 3'b001;
					end
				3'b001:
					begin
						r_wait <= 1;
						waits <= 3'b010;
					end
				default: 
					if (mreq==1)
					begin
						waits<=3'b000;
					end
			endcase
		// ROM = 2 wait states
		end else if (cs_rom == 0) 
		begin
				case (waits)
				3'b000:
					if ((mreq == 0) & ( (rd==0)|(wr==0)) )
					begin
						r_wait <= 0;
						waits <= 3'b001;
					end
				3'b001:
					waits <= 3'b010;
				3'b010:
					begin
						waits<=3'b011;
						r_wait<=1;
				   end
				3'b011:
					if (mreq==1)
					begin
						waits<=2'b00;
					end
			endcase
		end else if (cs_stebus==0)
		// STEBUS wait states
		begin
		case (waits)
				3'b000:
					if ((r_datastrobe==0) & (datack==1)) 
					begin
						r_wait <= 0;
						waits <= 3'b001;
					end
				3'b110: // timeout
						begin
						r_wait<=1;
						waits<=3'b111;
						end
				3'b111:
					if (mreq==1)
						begin
							waits <= 3'b000;
						end
				default:
					if (datack==1)
					begin
						waits <= waits+1;
					end
					else
					begin
						r_wait <=1;
						waits <= 3'b111; 
					end
					
			endcase
		end
		
	 end
	 
  endmodule 
  
  

  module z8s180_testbench;
  
    
	parameter PERIOD=1;
  
	reg clk;
	wire cs_ram,cs_rom,cs_bus;
	reg[2:0] addr;
	wire mem_wr,mem_rd;
	wire cm0,cm1,cm2,adrstrb,datatstrb;
   reg datack,trferr;
	reg iorq,mreq,m1,wr,rd;
	wire wt;
	wire busdir;
	
	z8s180 CPLD(clk,cs_ram,cs_rom,cs_bus,addr,mem_rd,mem_wr,cm0,cm1,cm2,adrstrb,datastrb,datack,trferr,busdir,iorq,mreq,m1,wr,rd,wt);
	
	initial
	begin
		clk=0;
	end
	
	always #PERIOD clk=~clk;
	
	initial
	begin
	
	$dumpfile("test.vcd");
     $dumpvars(0,z8s180_testbench);
		#0
	   addr=3'b000;
		mreq=1;
		iorq=1;
		m1=1;
		wr=1;
		rd=1;
		datack=1;
		trferr=1;
		
		#2
		addr=3'b001;
		#4
		addr=3'b010;
		#6
		addr=3'b011;
		#8
		addr=3'b100;
		#10
		addr=3'b101;
		#12
		addr=3'b110;
		#14
		addr=3'b111;
		
		#21
		mreq=0;
		#22
		rd=0;
		#23
		datack=0;
		
		#24
		datack=1;
		#25
		rd=1;
		mreq=1;
		#31
		mreq=0;
		#32
		wr=0;
		#33
		wr=1;
		datack=0;
		#34
		datack=1;
		mreq=1;
		#41
		mreq=1;
		#45
		addr=3'b000;
		#50
		mreq=0;
		#60
		mreq=1;
		#65 $finish;
   end
  
  endmodule

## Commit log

2019-12-07 kicad - stebus
    [stebus-B_Cu.gbr, stebus-B_Mask.gbr, stebus-B_Paste.gbr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]
2020-01-12 vdu update
    [sound_register.ods, vdu.csv]
2020-05-01 3d files
    [#bottom.dxf, bottom.dxf, front_corner.f3d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]
2020-05-01 back corner
    [back_corner.f3d, back_corner.step, back_corner.stl]
2020-05-02 front in
    [#front_in.dxf, front_in.dxf]
2020-05-09 top psu
    [#top_psu.dxf, top_psu.dxf]
2020-05-09 dxf bugfix
    [side_left.dxf, top_psu.dxf]
2020-05-17 repo cleanup
    [#back.dxf, #back_psu.dxf, #bottom.dxf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]

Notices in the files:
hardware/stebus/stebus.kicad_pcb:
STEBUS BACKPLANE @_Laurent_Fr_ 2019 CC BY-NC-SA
